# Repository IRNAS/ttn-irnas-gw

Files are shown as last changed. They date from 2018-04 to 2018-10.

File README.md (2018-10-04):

# Build and configure your own LoraWAN Gateway from The Things Conference On Tour in Maribor!

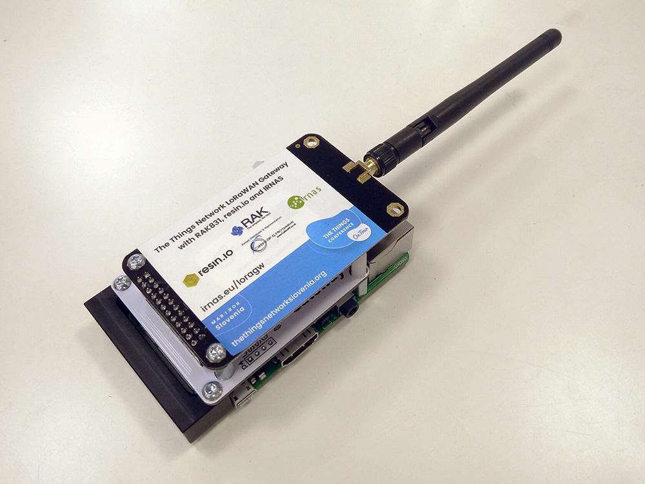
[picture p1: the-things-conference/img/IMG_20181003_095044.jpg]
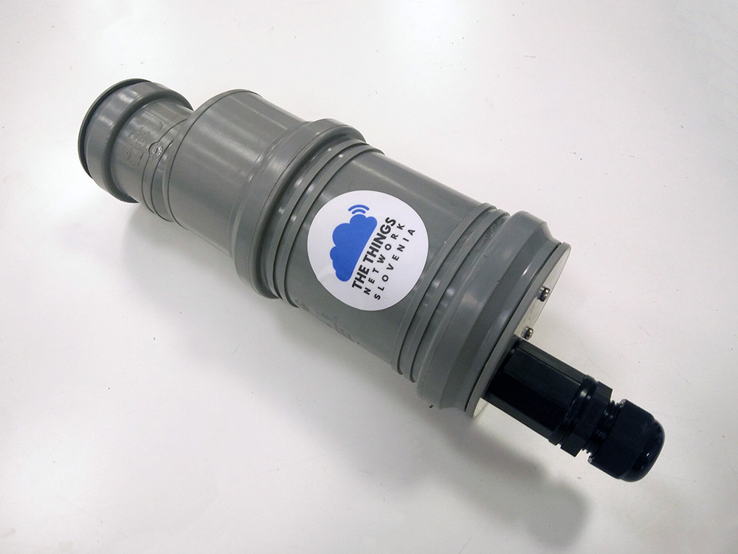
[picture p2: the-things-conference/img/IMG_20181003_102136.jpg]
   **Instructions available [HERE](https://github.com/IRNAS/ttn-irnas-gw/tree/master/the-things-conference/README.md).**

# LoraWAN gateway for TheThingsNetwork

To boost the growth of cost-effective community established outdoor gateways we have designed IRNAS outdoor LoraWAN gateway that includes all components and an antenna element in a weatherproof enclosure. This way communities can easily deploy good quality gateways with minimal costs. Currently there are a number of different designs available:
 1. TheThingsConference Slovenia GW RPi 3b+ using resin.io and RAK831 (latest), optional external antenna, optional 3G uplink
 1. RPi Zero W and RAK831/IMST iC880A

# TheThingsConference Slovenia gateway LoraWAN gateway RAK wireless RAK831, Raspberry Pi 3B+ with resin.io and IRNAS connecting PCB
This gateway desing is the latest in series of the gateways, optimized for simple assembly and reliable outdoor operation. It is available in basic and external antenna configurations:

* Components of basic version
  * RAK wireless RAK831 gateway module http://www.rakwireless.com/en/WisKeyOSH/RAK831 (TheThingsNetwork Conference on Tour Maribor units sponsored by RAK wireless)
  * IRNAS https://github.com/IRNAS/RPi-HAT-RAK831-PoE PCB (TheThingsNetwork Conference on Tour Maribor units sponsored by IRNAS)
  * Raspberry Pi 3B+ (TheThingsNetwork Conference on Tour Maribor units sponsored by resin.io)
  * micro SD card 16GB (TheThingsNetwork Conference on Tour Maribor units sponsored by resin.io)
  * Waterproof PoE connector (TheThingsNetwork Conference on Tour Maribor units sponsored by resin.io)
  * Polyethilene tubing for enclosure (TheThingsNetwork Conference on Tour Maribor units sponsored by resin.io)
  * 24V Passive PoE injector/power supply (TheThingsNetwork Conference on Tour Maribor units sponsored by IRNAS)

* Components of upgrade
  * SMA to N-connector adapter
  * RAK wireless 4dB 868MHz antenna
  * Pipe mounts for installing the GW outdoors

# TheThingsNetwork LoraWAN gateway with RAK831 / IMST iC880A and RaspberryPi Zero W for outdoor use. DIY 5.5dB colinear antenna or N connector antenna.

There are two key design options available, subject to selecting the antenna:
* DIY colinear antenna with designed gain of 5.5dB, typically build quality reducsed this to about 3dB (shown left)
* N-connector option for other antennas, default option is RAK wireless omni glass fiber antenna 6dB (design files to be avilable shortly) (shown right)

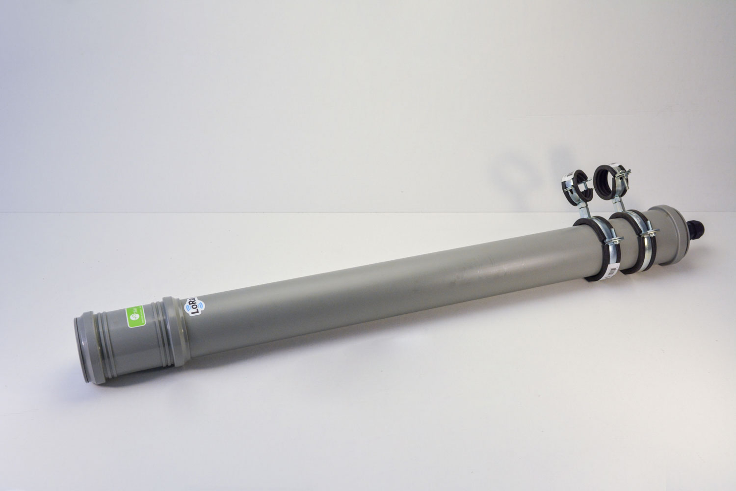
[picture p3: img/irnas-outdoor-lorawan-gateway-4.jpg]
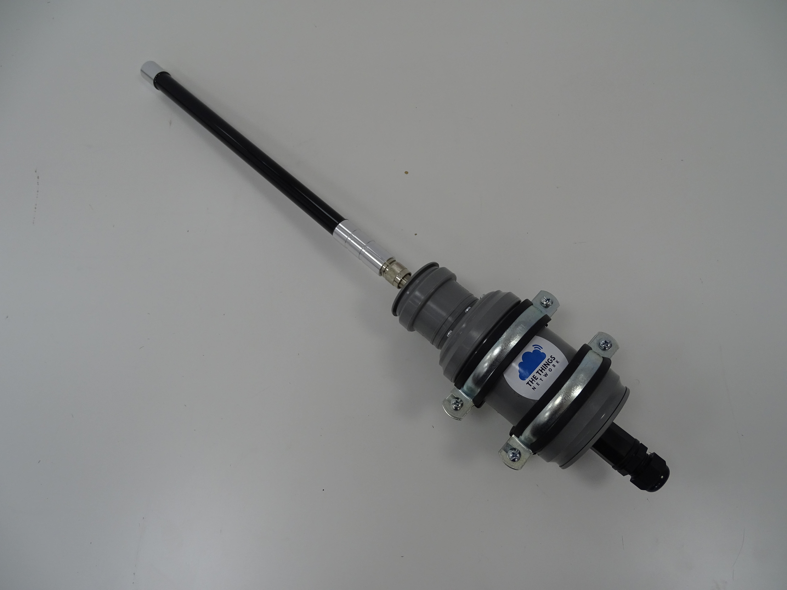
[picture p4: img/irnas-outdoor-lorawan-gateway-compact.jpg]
  

IRNAS outdoor LoraWAN gateway joins great solutions into an unified gateway:

* RAK Wireless RAK831 concentrator option:
  * RAK wireless RAK831 gateway module http://www.rakwireless.com/en/WisKeyOSH/RAK831
  * RAK-Raspberry Pi shield by ch2i https://github.com/hallard/RAK831-Zero

* IMST iC880A concentrator option:
  * IMST ic880A concentrator https://wireless-solutions.de/products/radiomodules/ic880a.html
  * iC880A RPi shield/backplane https://www.tindie.com/products/gnz/imst-ic880a-lorawan-backplane-kit/
  * note this backplane requires a minor manual modification to install Murata OKI-78SR-5 regulator, untill an optimized version is designed, check photosfor details

* Components used in both versions
  * Murata OKI-78SR-5 power regulator (multiple versions available)
  * Raspberry Pi Zero W embedded computer + SD card https://www.raspberrypi.org/products/raspberry-pi-zero-w/
  * micro USB-Ethernet USB 2.0 adapter: https://www.aliexpress.com/item/PZ-USB-2-0-to-fast-Ethernet-10-100-RJ45-Network-LAN-Adapter-Card-Micro-usb/32819958748.html
  * Waterproof PoE injector http://szzq.en.alibaba.com/product/60307069118-209893270/IP67_waterproof_RJ45_ethernet_cable_connector.html
  * DIY 5.5dB co-linear antenna designed by Fabien Ferrero from UNICE in France
  * Polyethilene tubing for enclosure 75mm diameter
  * 3D printed part by IRNAS to mount everything together
  * 24V Passive PoE injector/power supply
  * Optional INA219 current measurement board via I2C

The final product is a simple and and cost-effective gateway for about 250 EUR anyone can make and simply install outdoor. With this design we have achieved over 50 km coverage between Pohorje mountain and cities of Graz in Austria and Zagreb in Croatia.

## Assembly instructions
Assembly instructions are coming up shortly, however the posted images are sufficient for replicating the design. The only custom mechanical part that can be 3D printed or milled available in this repository in the folder: mount and on [this link](https://a360.co/2HcsiBF).

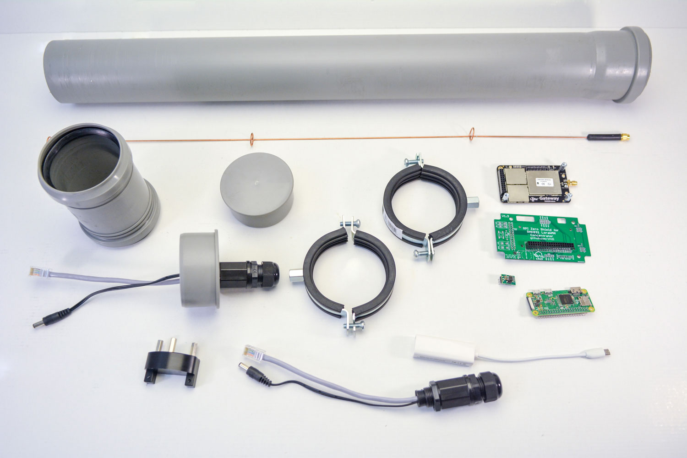
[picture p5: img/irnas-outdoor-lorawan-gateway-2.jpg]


RAK Wireless RAK831 concentrator option

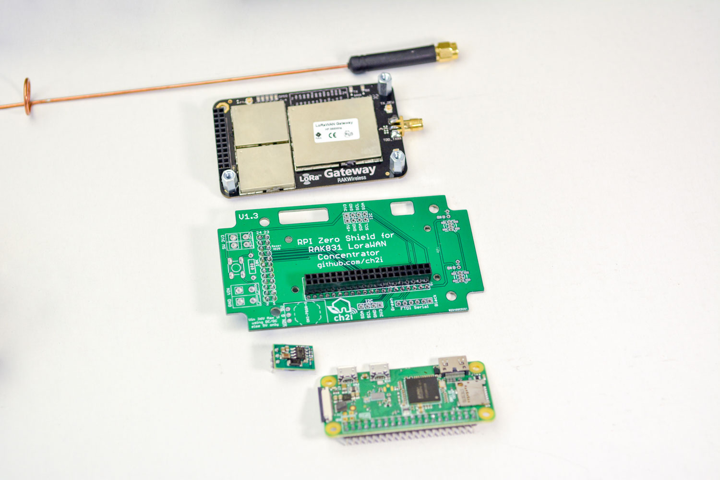
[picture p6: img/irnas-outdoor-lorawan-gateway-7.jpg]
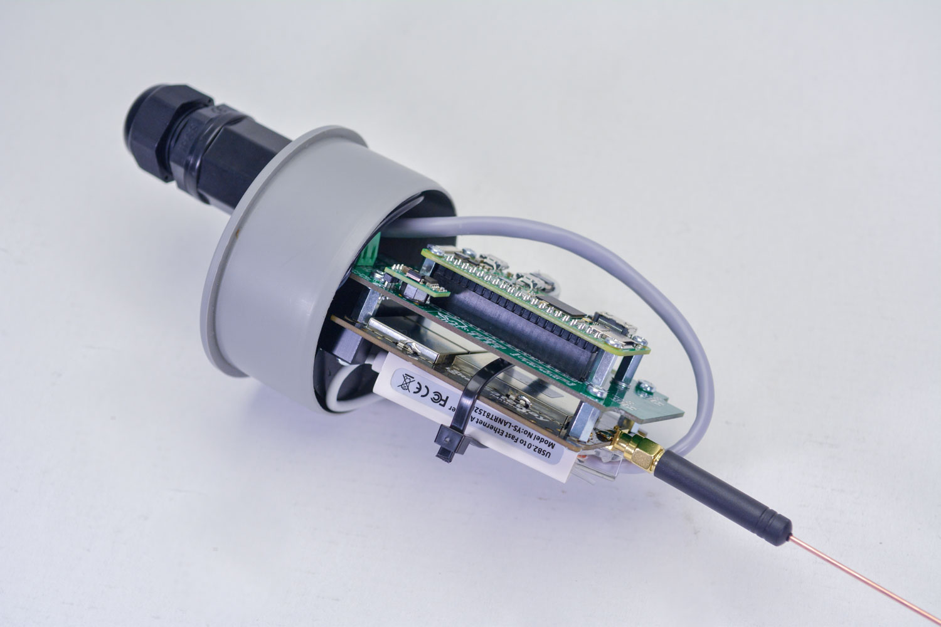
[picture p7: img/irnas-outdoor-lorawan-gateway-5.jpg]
 

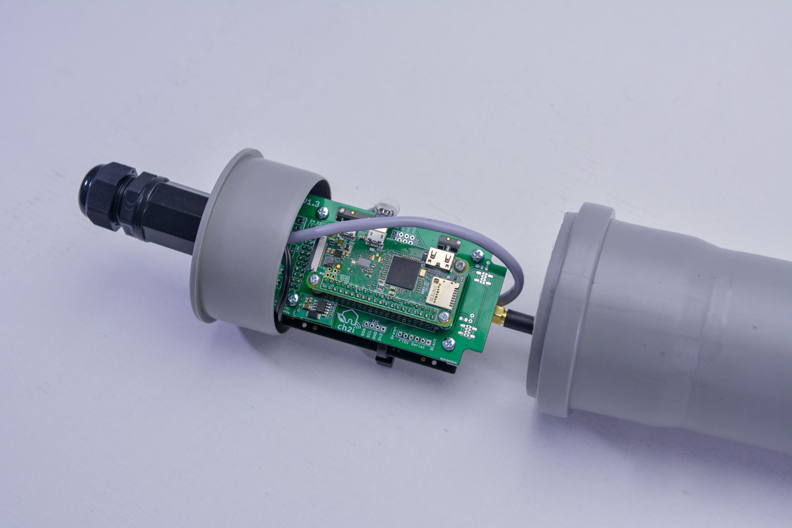
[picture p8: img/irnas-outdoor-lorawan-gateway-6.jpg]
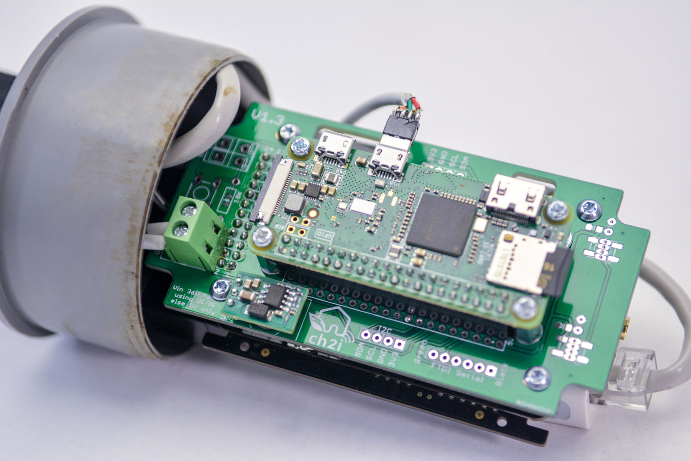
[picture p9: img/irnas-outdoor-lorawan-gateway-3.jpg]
 

IMST iC880A concentrator option

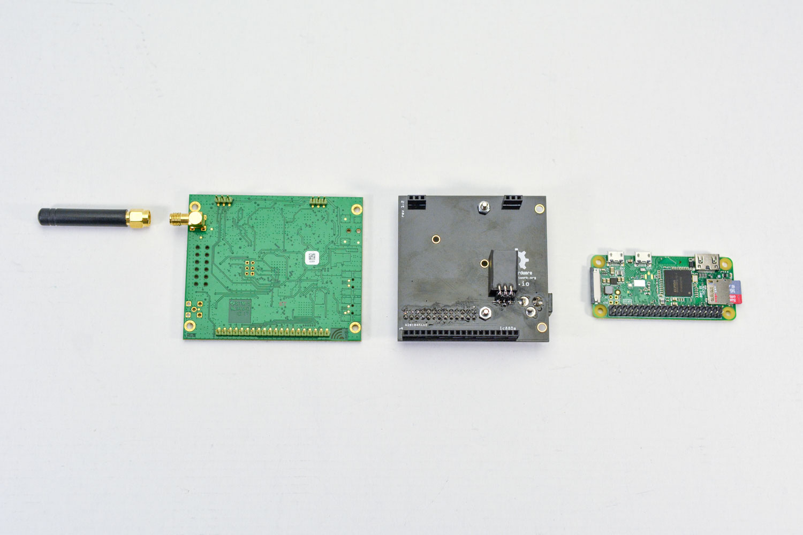
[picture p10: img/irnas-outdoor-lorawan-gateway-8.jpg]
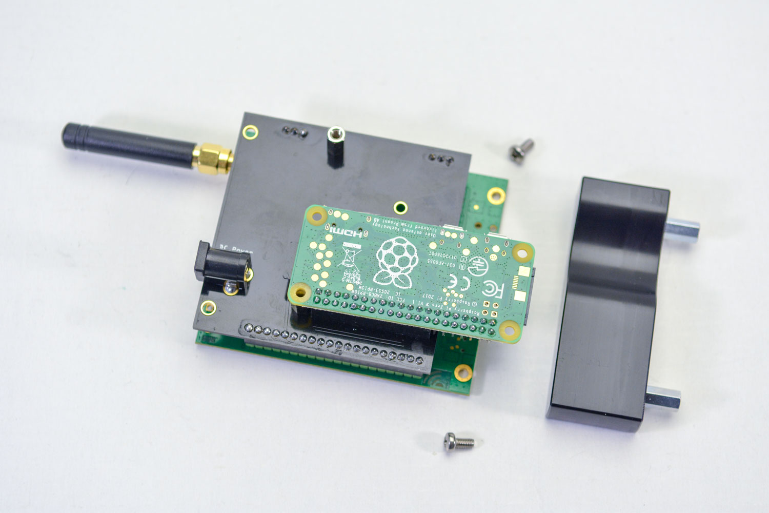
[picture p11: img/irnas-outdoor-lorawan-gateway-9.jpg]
 

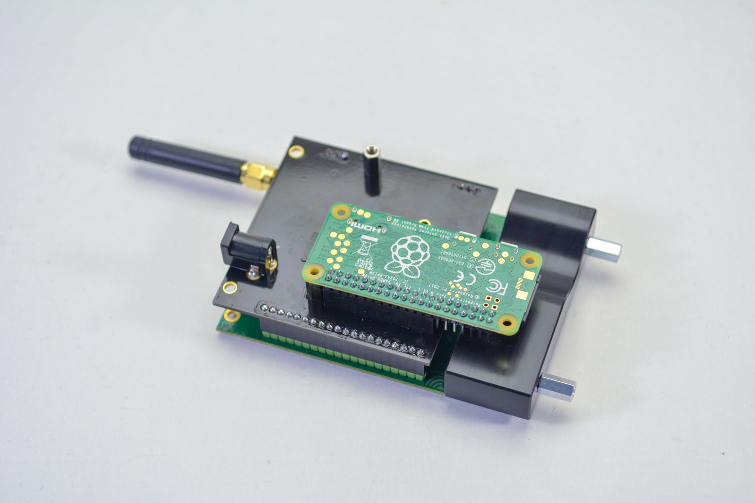
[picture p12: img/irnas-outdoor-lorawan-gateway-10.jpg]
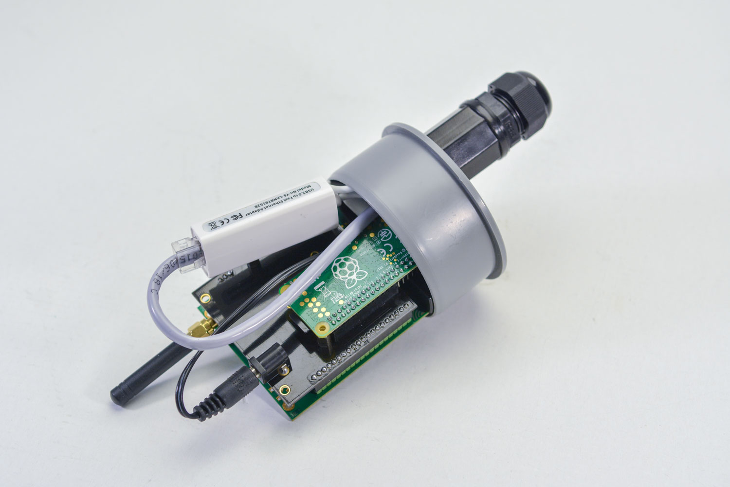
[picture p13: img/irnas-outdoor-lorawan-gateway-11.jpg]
 



## Co-linear antenna wire
Bending the wire for the co-linear 5.5dB antenna is likely the most challenging part and requires special care. Note that the frequency is tuned with the diameter of the loop and thus it must be made rather precisely. There are two antenna designs available, [one for 868MHZ EU](Collinear868MHzLoRaantenna.PDF) and [the other for 915MHz USA](CollinearLoRaantenna915MHzIRNAS.pdf). Step-by-step instructions on how to make the antenna available in this [video tutorial](https://youtu.be/1_1LxuOngHs).

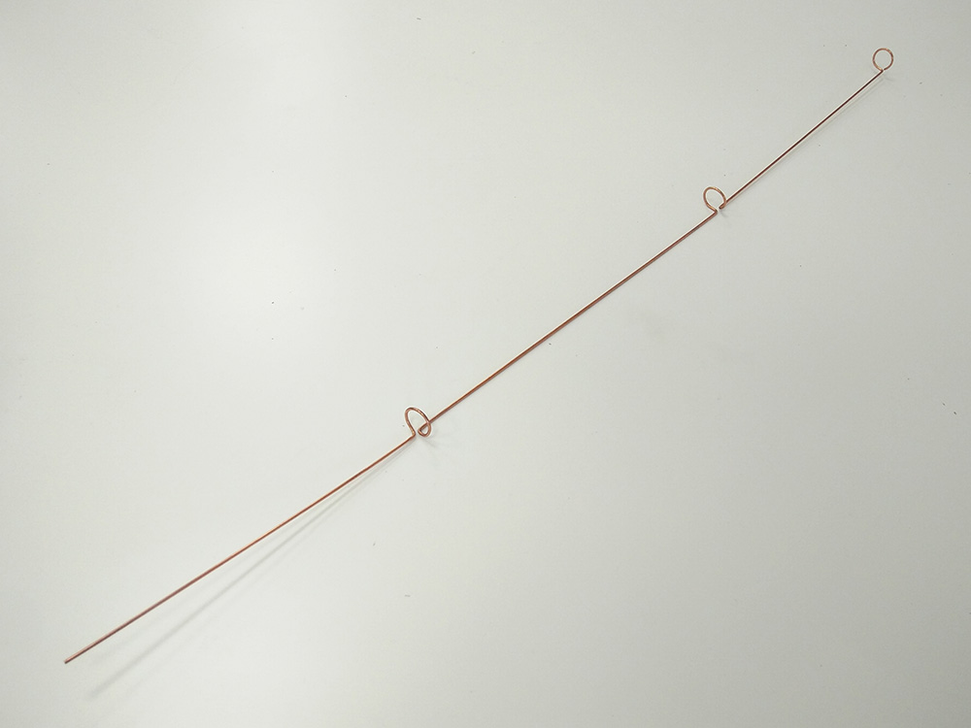
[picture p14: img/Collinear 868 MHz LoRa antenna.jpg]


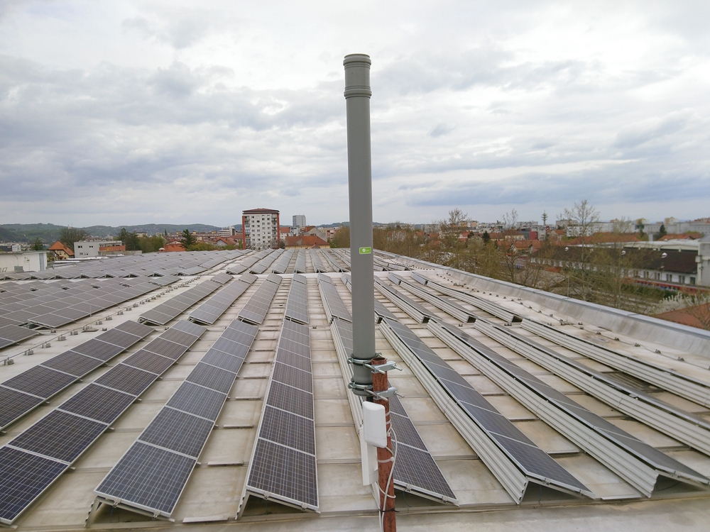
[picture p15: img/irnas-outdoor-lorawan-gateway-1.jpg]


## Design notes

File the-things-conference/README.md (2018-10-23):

# LoraWAN Gateway configuration

Slides from the workshop at The Things Conference On Tour in Maribor that will help you to configure your own LoraWAN gateway are available [HERE](https://speakerdeck.com/pimterry/build-your-own-ttn-gateway-with-resin-dot-io-and-rak-wireless). If you need any help or have any questions do not hesitate to [contact us](https://www.irnas.eu/contact/).

 

:warning: ***Attention: There is a mistake on the slides from the workshop. On the slide 12 of the instructions the GW_RESET_PIN is set to 11 but it should be set to 22 instead.***

# Assembly instructions for waterproof housing

The next steps will help you to assemble the waterproof housing for the LoraWAN Gateway and prepare it for the outdoor mounting.

Take the assembled electronics stack, consisting of Raspberry Pi and RAK Wireless RAK831 concentrator.

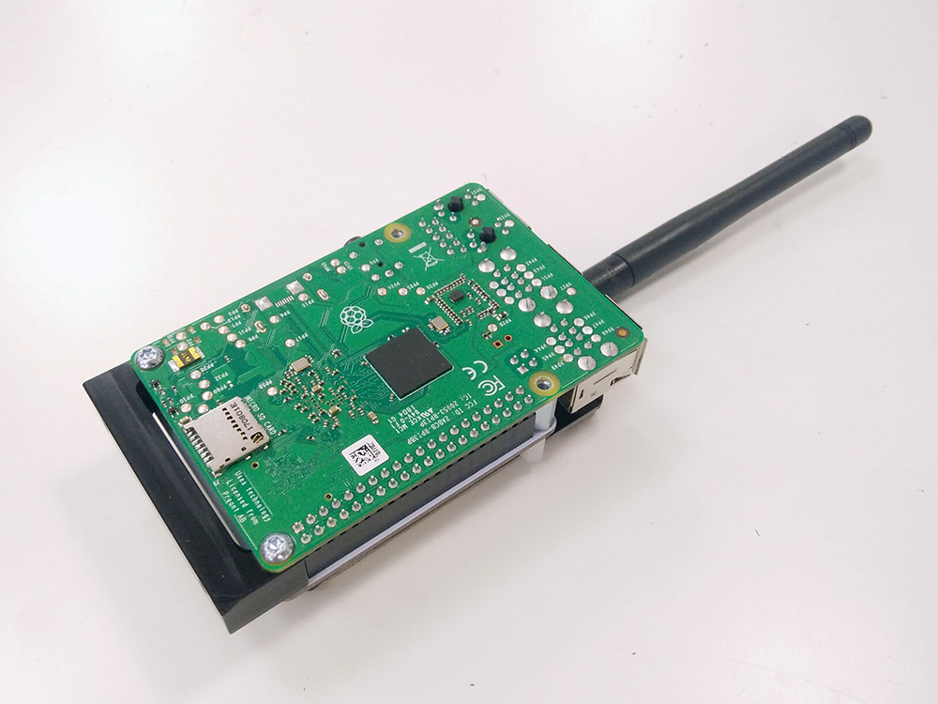
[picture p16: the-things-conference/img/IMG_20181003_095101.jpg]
 

Prepare and insert the micro SD card into the Raspberry Pi.

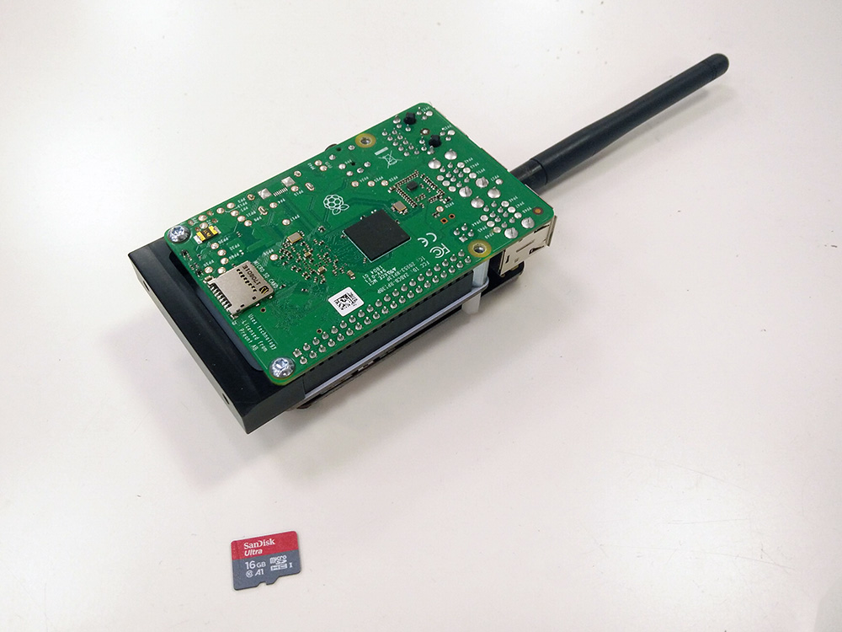
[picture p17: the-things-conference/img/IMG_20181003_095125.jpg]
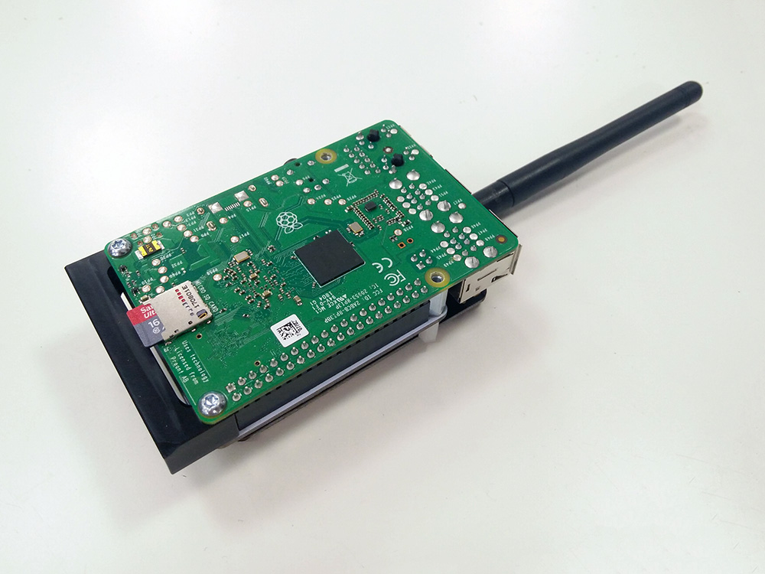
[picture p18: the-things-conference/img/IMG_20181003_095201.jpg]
 

Take the larger plastic lid and attach the ethernet cable gland.

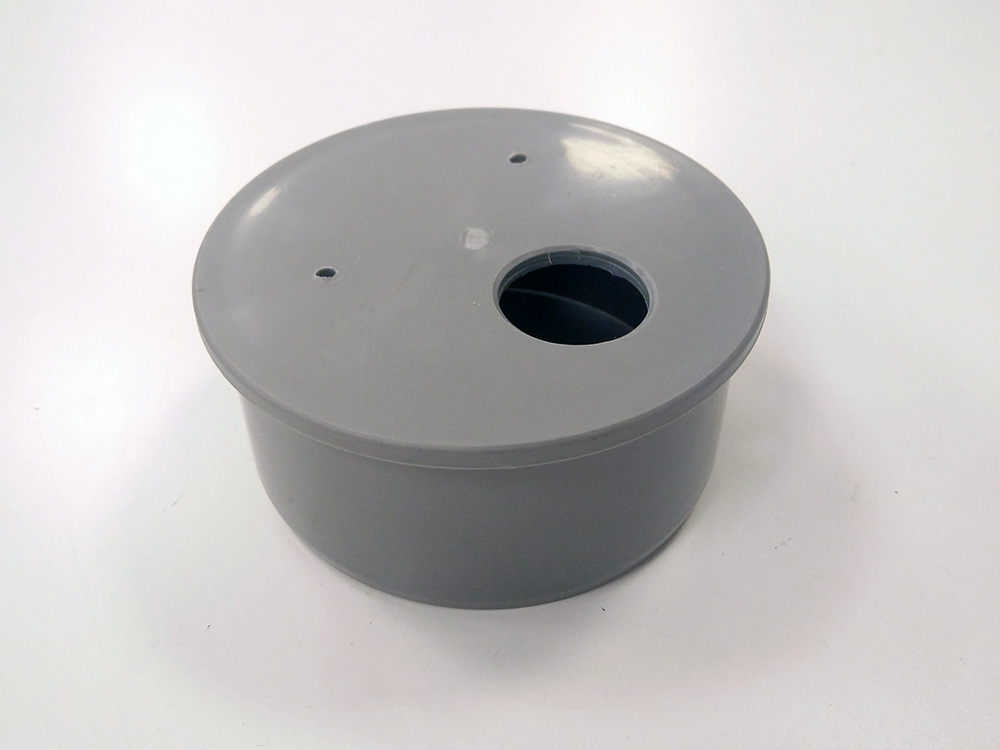
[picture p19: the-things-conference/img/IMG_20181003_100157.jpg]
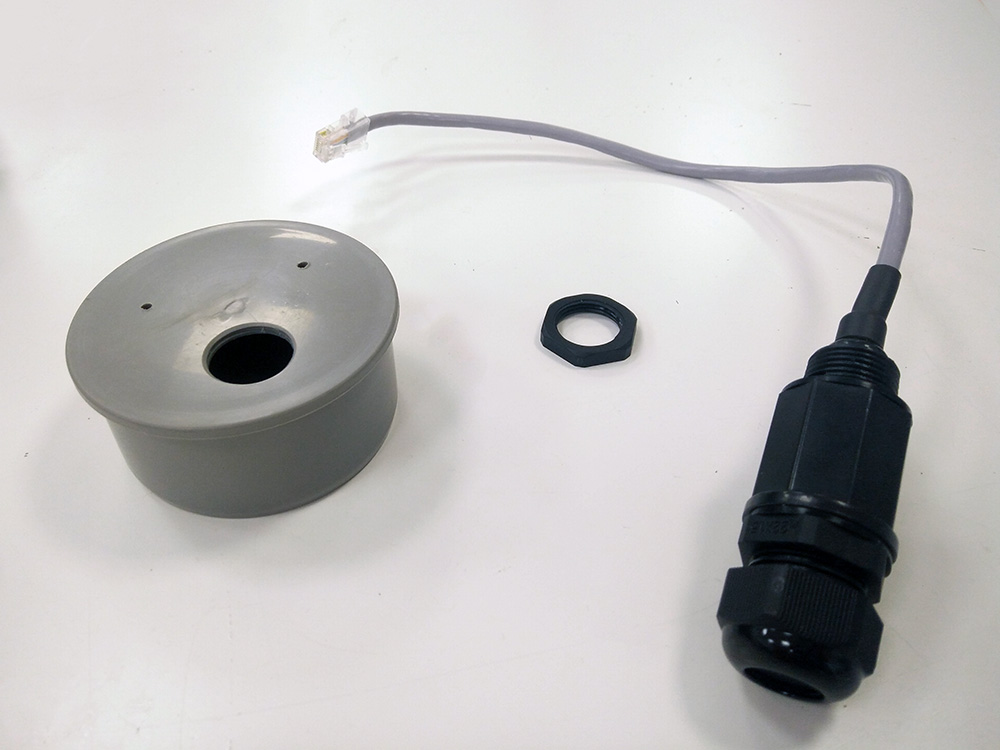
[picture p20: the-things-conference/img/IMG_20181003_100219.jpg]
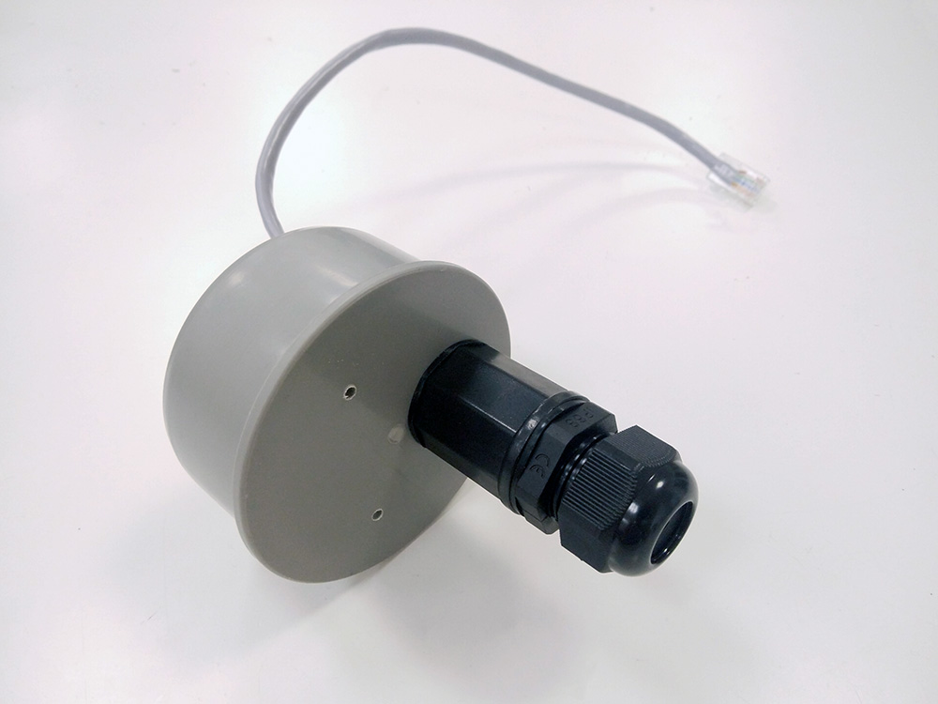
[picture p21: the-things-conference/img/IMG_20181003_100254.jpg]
  

Attach the electronics stack using two screws (size M3x5).

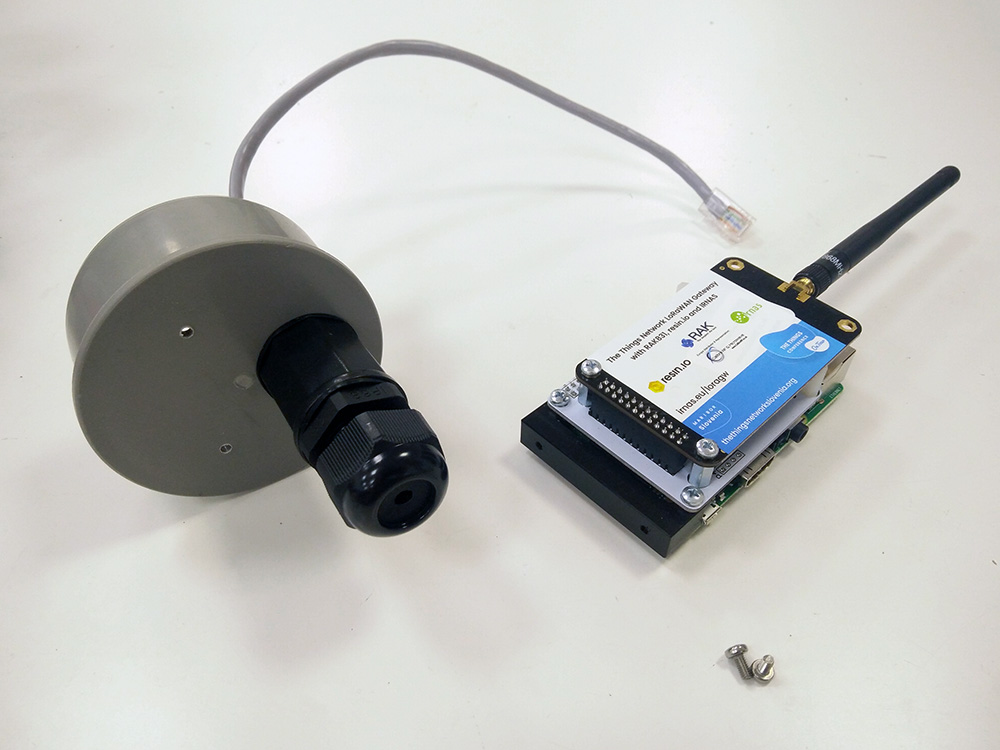
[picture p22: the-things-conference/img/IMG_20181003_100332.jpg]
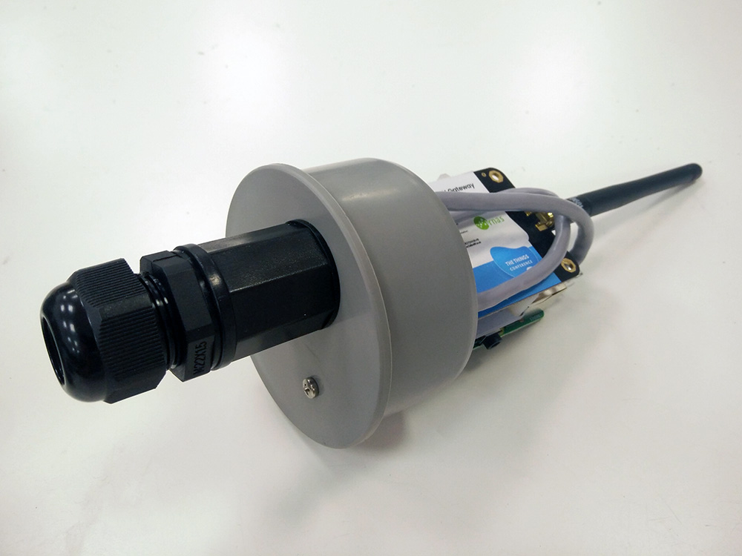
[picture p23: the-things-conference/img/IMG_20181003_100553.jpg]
 

Take the remainig parts of plastic housing and insert the smaler lid into the smaler tube.

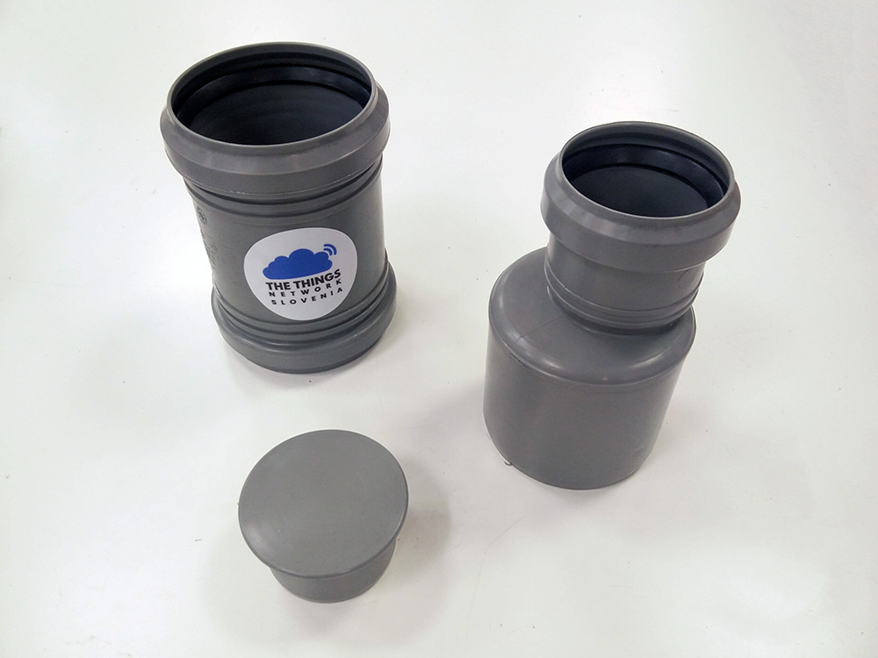
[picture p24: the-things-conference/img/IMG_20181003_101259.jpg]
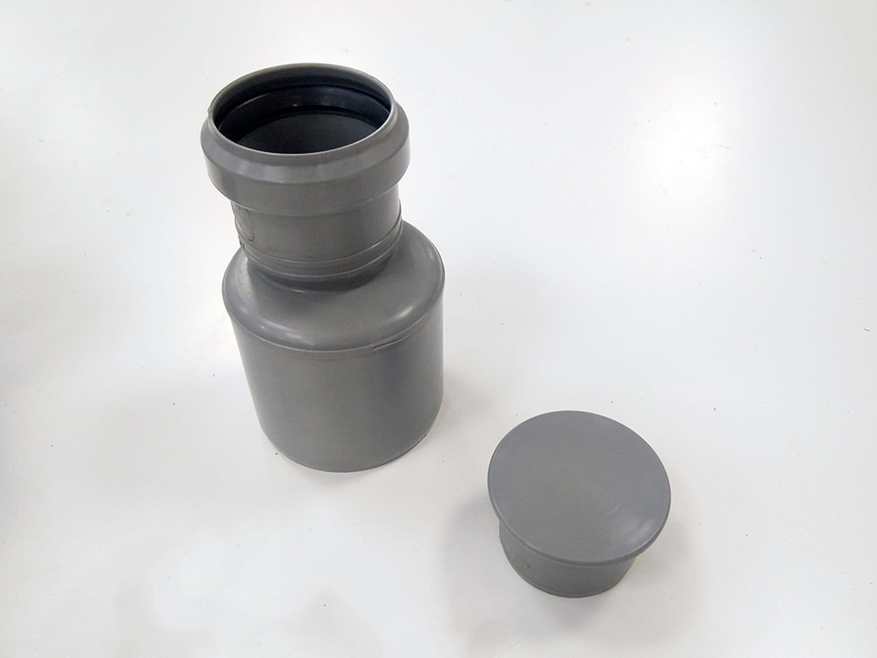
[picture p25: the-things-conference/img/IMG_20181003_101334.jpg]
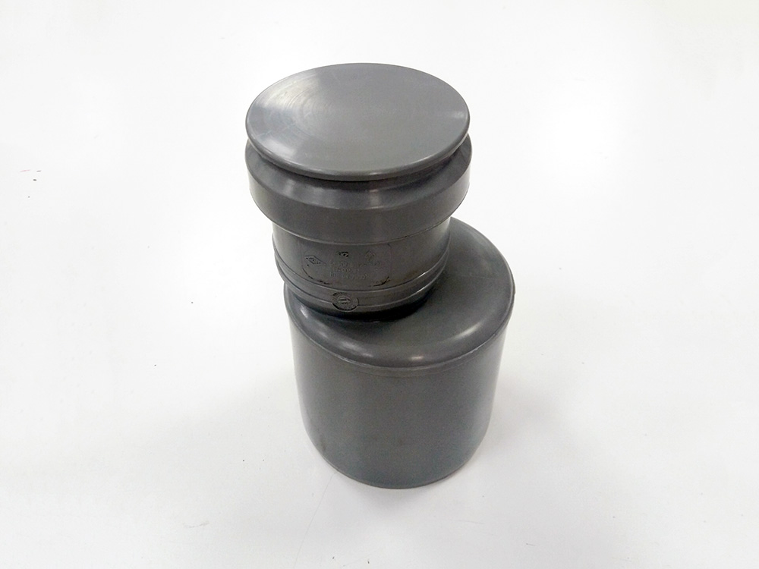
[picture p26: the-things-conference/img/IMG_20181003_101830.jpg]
  

Insert the larger lid with electronics into the larger tube.

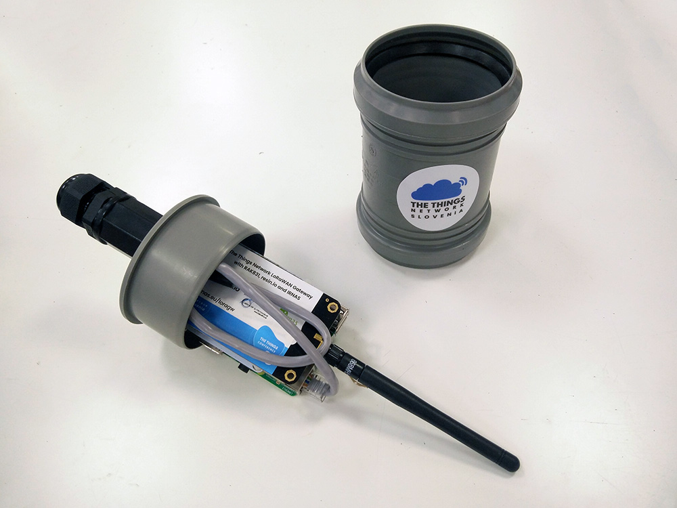
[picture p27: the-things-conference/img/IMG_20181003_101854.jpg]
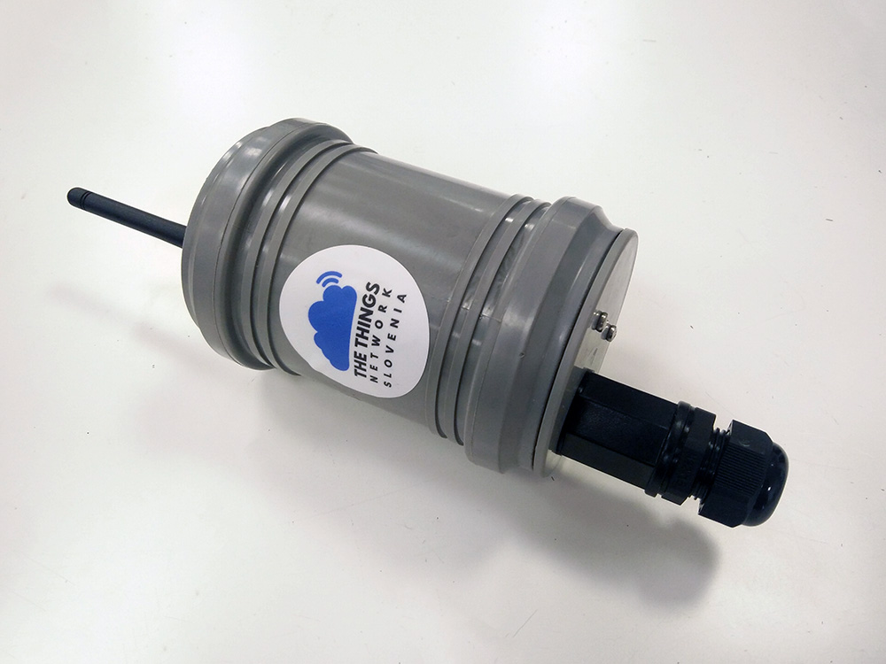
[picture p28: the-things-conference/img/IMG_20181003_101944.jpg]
 

Insert the smaler tube into the larger tube. Be careful not to damage the antenna - DO NOT insert the smaller tube all the way into the larger tube.

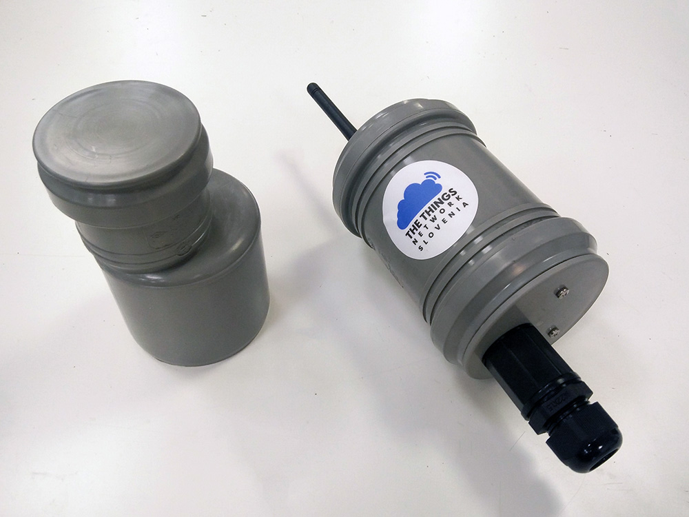
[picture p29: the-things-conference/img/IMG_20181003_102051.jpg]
 

## External antenna upgrade

The next steps will help you to assemble and attach the external antenna upgrade kit. If you would like to upgrade your LoraWAN Gateway with an external antenna please [contact us](https://www.irnas.eu/contact/).

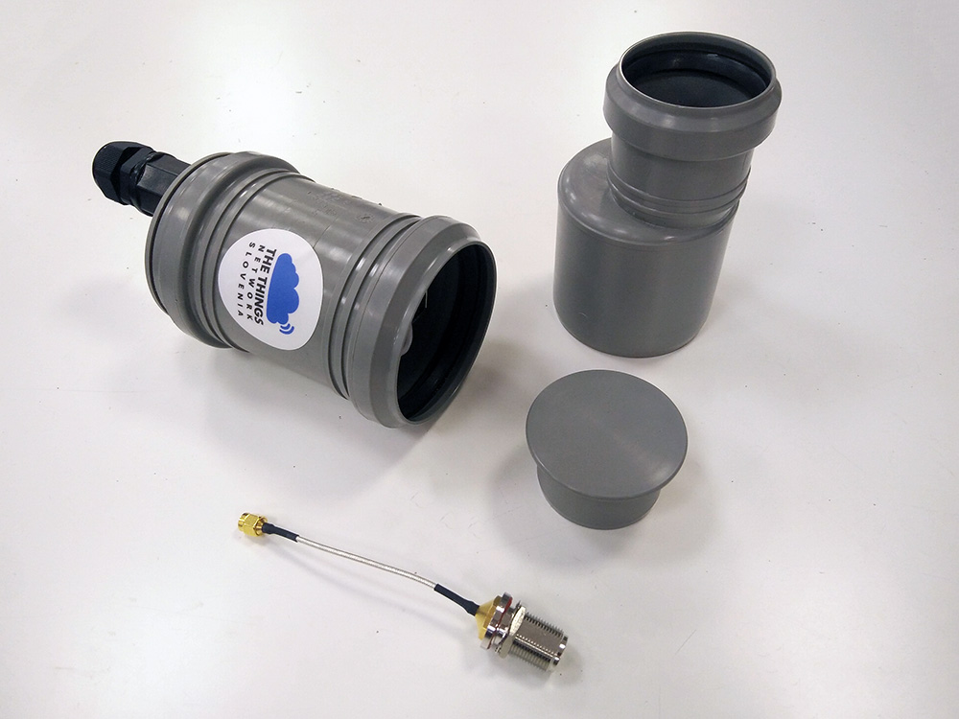
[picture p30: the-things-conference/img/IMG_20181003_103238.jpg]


Take the smaller lid and drill a hole in the center of the lid.

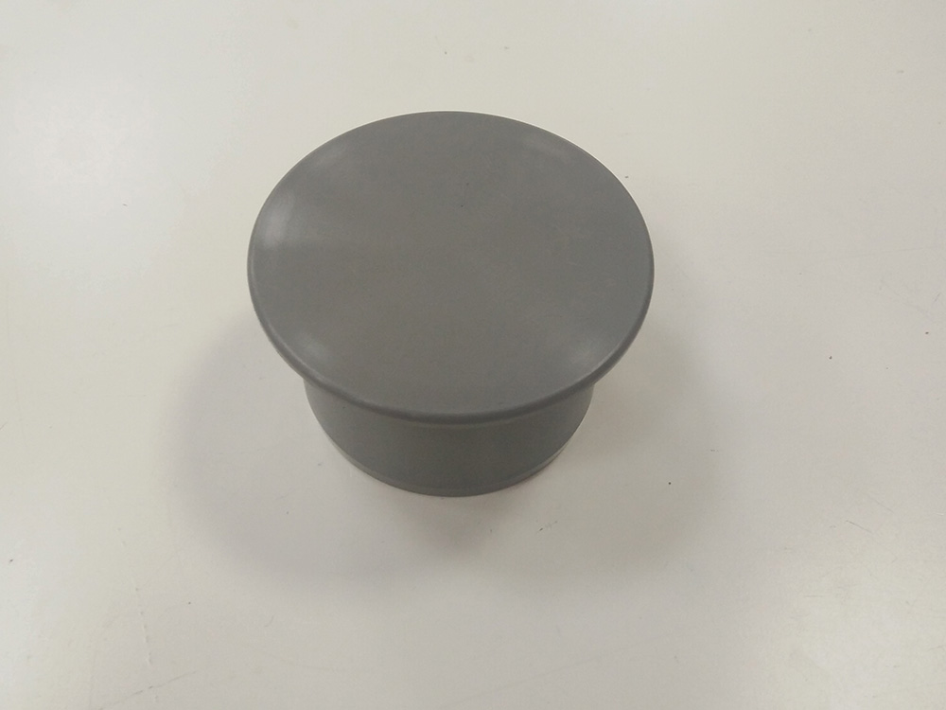
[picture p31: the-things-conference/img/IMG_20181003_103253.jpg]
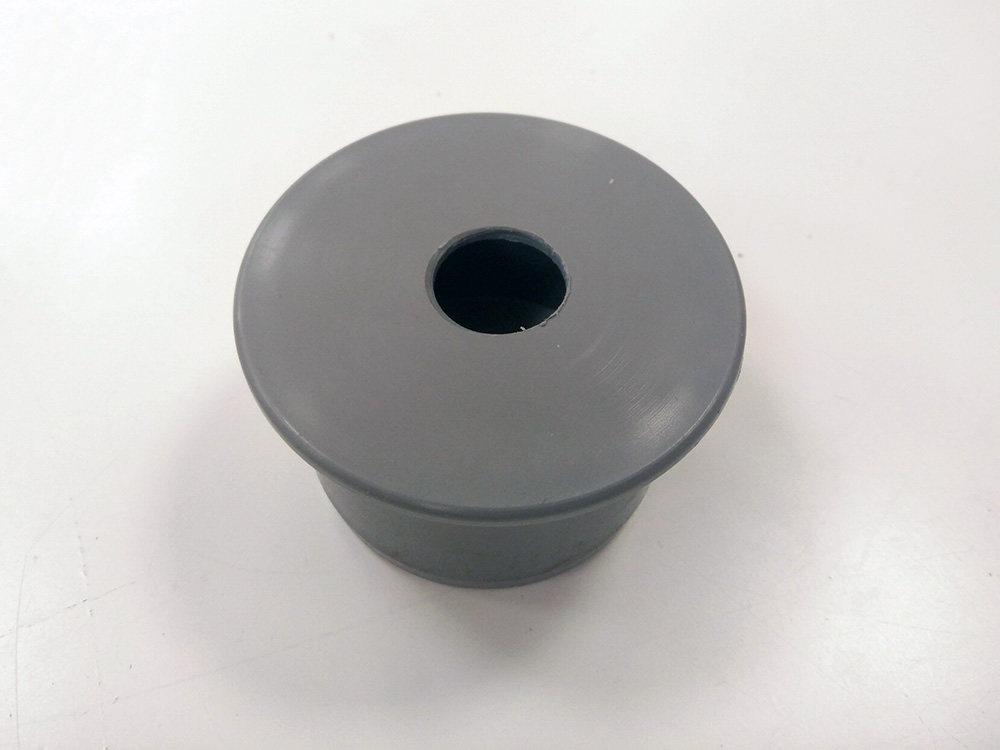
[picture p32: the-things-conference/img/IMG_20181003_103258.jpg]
 

Connect the antenna adapter to the RAK Wireless RAK831 concentrator.

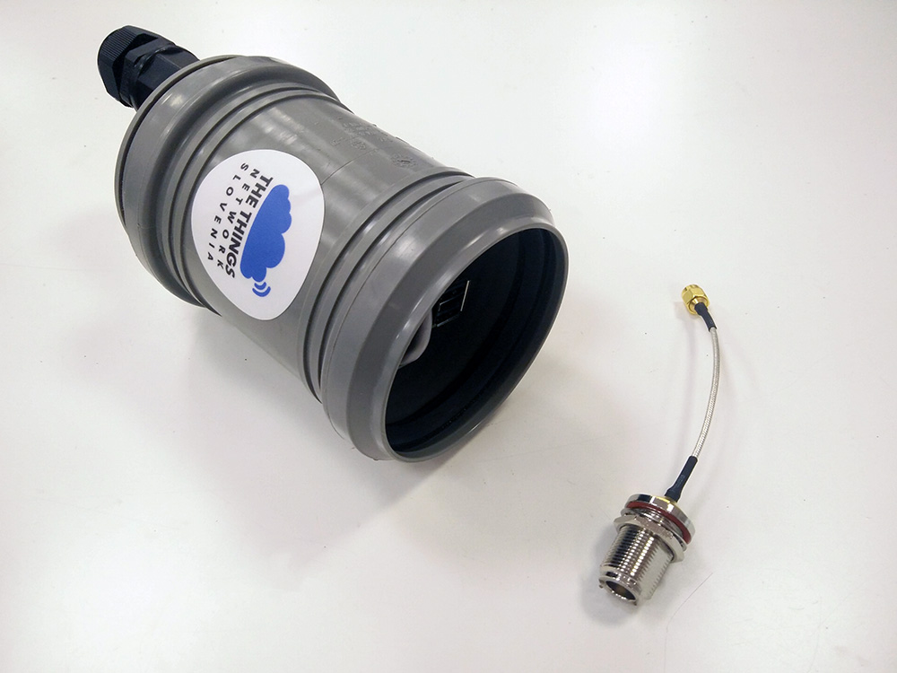
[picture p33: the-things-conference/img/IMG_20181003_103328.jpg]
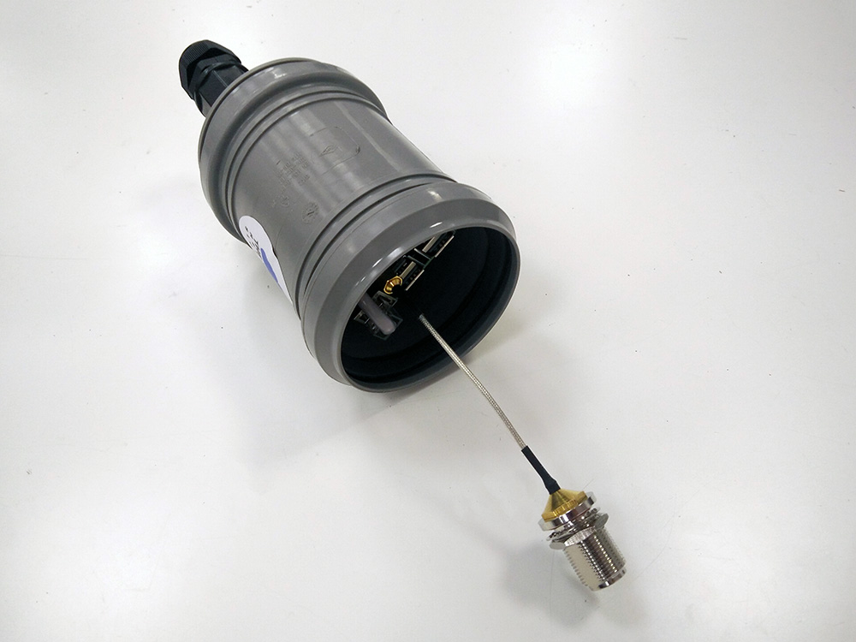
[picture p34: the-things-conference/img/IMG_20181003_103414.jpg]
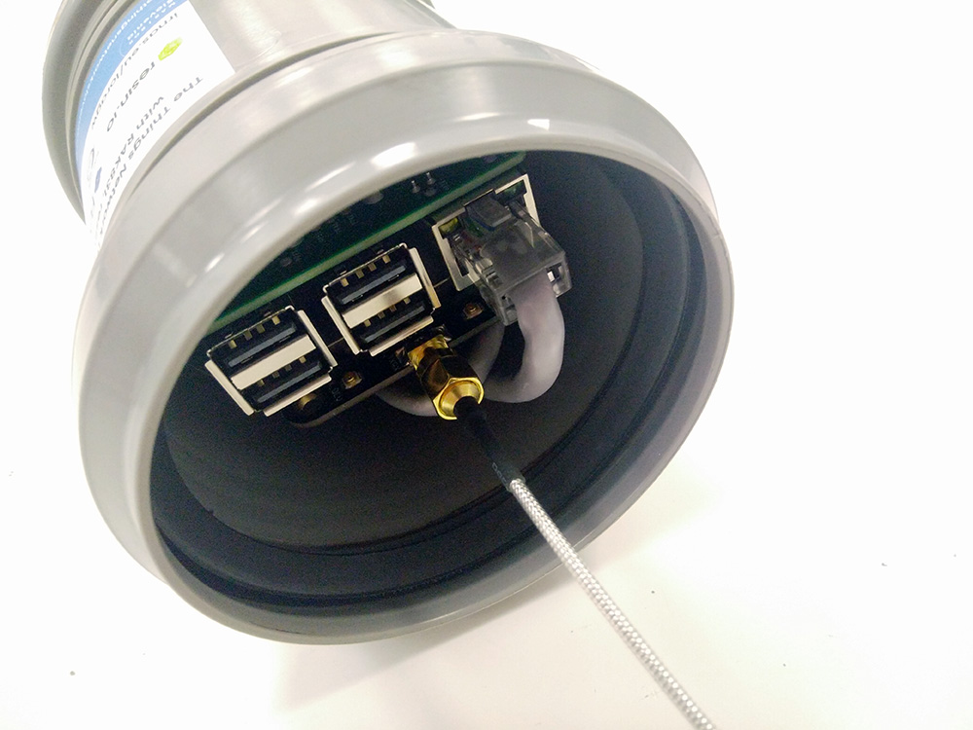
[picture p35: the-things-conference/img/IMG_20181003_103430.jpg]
  

Insert the smaller tube all the way into the larger tube.

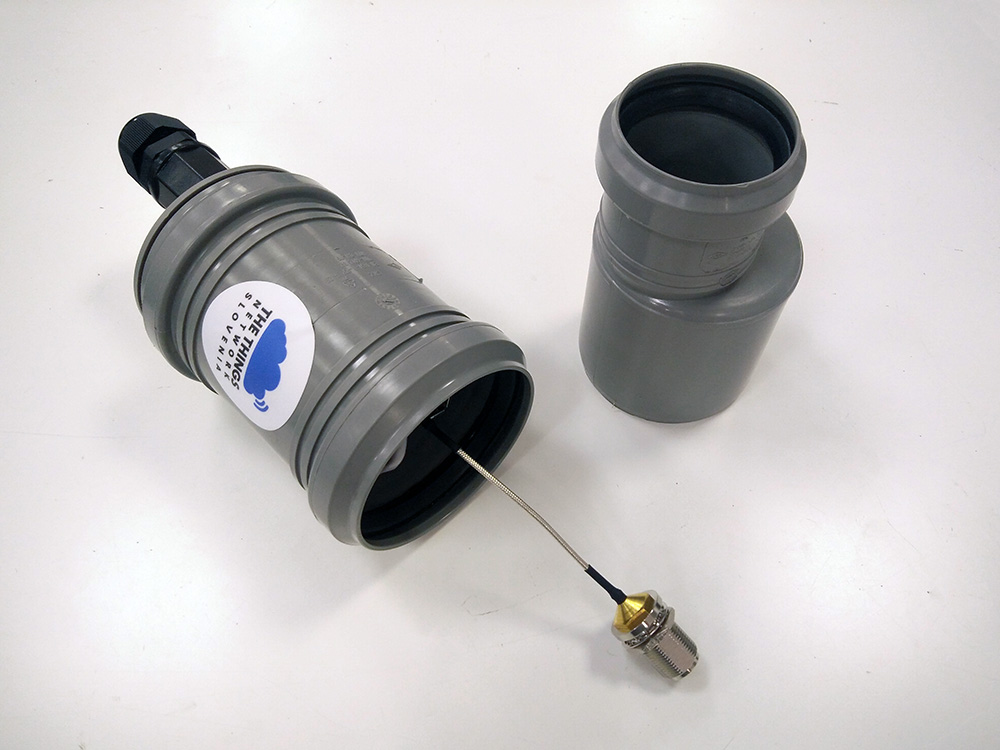
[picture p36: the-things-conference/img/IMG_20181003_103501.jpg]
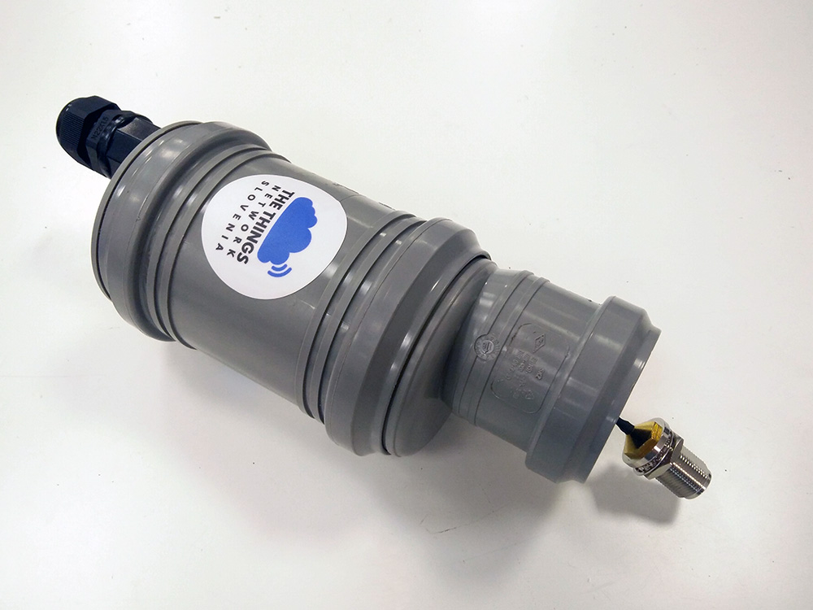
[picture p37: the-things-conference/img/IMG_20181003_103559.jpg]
 

Attach the antenna adapter to the smaler lid and insert the smaller lid into the tube.

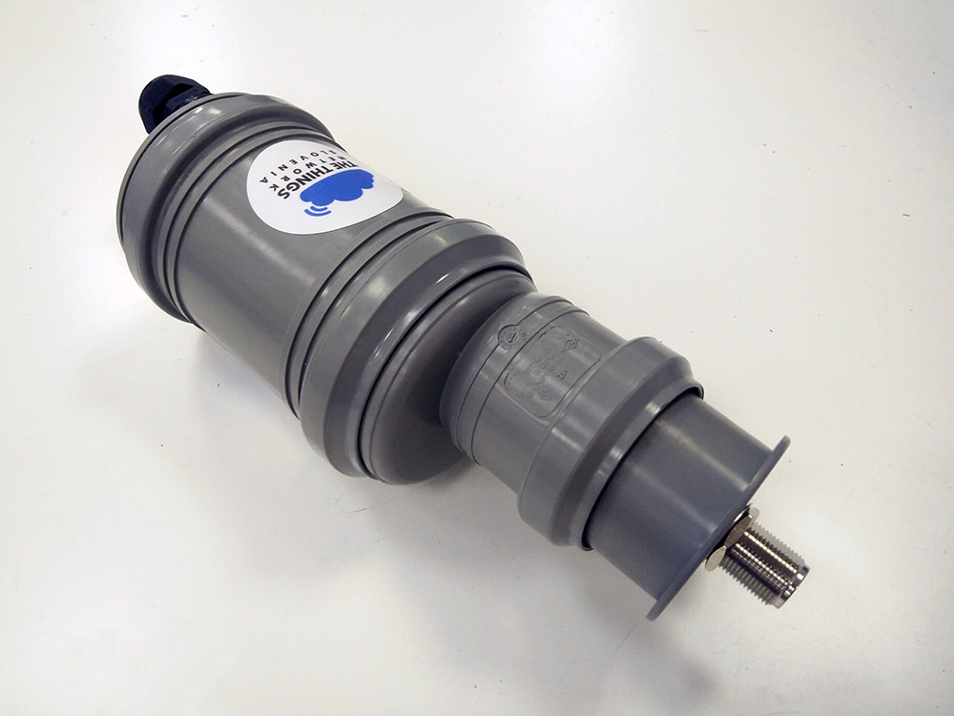
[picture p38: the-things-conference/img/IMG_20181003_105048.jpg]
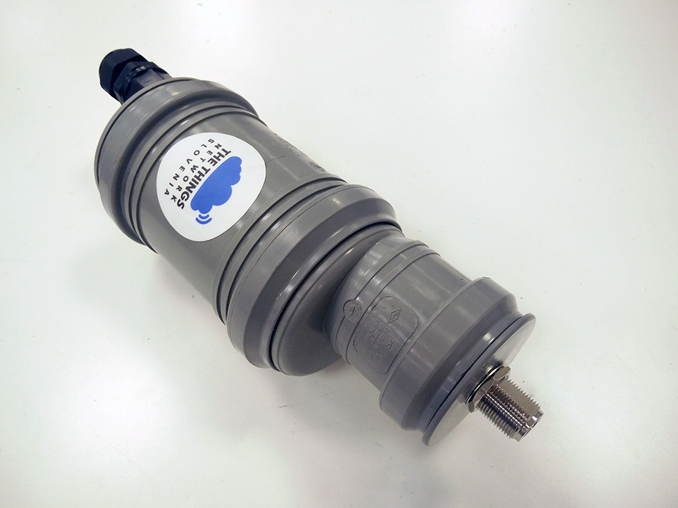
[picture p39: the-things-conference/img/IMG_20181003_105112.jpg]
 

Attach the antenna.



## Mounting upgrade

The next steps will help you to assemble and attach the mounting upgrade kit. If you would like to upgrade your LoraWAN Gateway with a mounting kit please [contact us](https://www.irnas.eu/contact/).

Assemble monuting clips.

 

Attach the mounting clips onto the gateway housing.



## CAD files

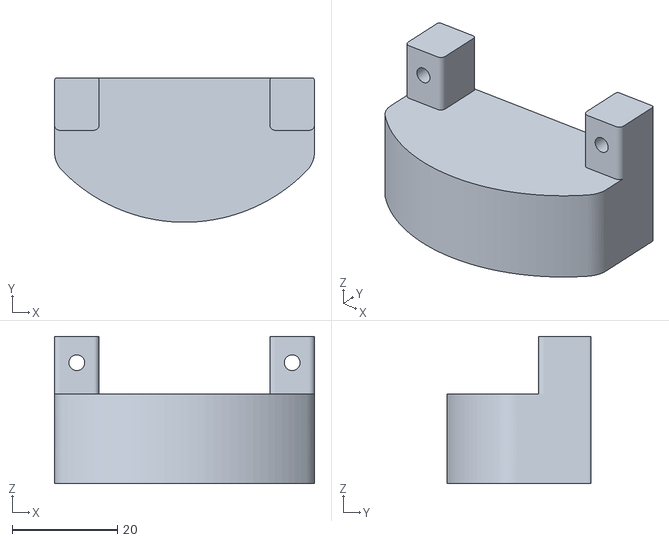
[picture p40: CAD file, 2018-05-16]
mount/lora antena base 1.stl
49.5 x 27.5 x 28.0

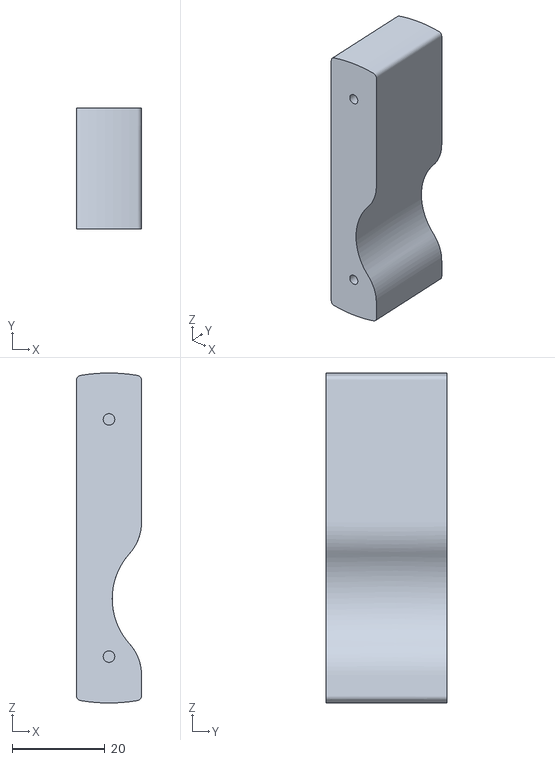
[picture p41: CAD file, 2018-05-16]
mount/lora antena base 2.stl
14.0 x 26.0 x 71.0

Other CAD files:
mount/Lora base piece.step
mount/Lora base piece.stl

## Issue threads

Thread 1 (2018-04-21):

Link to PoE adapter?

terrillmoore, 2018-04-21:
Lovely project!  I was following links, and I notice that the following link is incomplete:

> - USB-Ethernet adapter and Waterproof PoE injector https://www.aliexpress.com/item/High-Quality-5-Pin-Micro-USB-2-0-To-RJ45-LAN-Ethernet-Network-Adapter-100Mbps-For/32789232255.html

The link leads to the USB-Ethernet adapter, but that page doesn't have a PoE adapter.

--Terry

RussNelson, 2018-04-21:
I ordered this one, which seems to be what they're using: https://www.aliexpress.com/item/RJ45-PoE-Splitter-Separator-Female-male-Output-Connector-Plug-Power-Over-Ethernet-Outdoor-Waterproof-Adapter-Cable/32779527743.html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

RussNelson, 2018-04-21:
That's a passive splitter. Just routes the power over the unused Ethernet pairs. I also ordered these two from Amazon: https://www.amazon.com/gp/product/B007Q87KP2/ref=oh_aui_detailpage_o00_s00?ie=UTF8&psc=1
and https://www.amazon.com/gp/product/B01K4S7AEG/ref=oh_aui_detailpage_o02_s00?ie=UTF8&psc=1
They are standards-compliant and transmit 15W @12V using 48V.
The standard requires signalled power-on and short protection, whereas the passive splitter is just wires. That's reflected in the 6X multiplier to get standards compliance.

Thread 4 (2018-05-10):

Ethernet micro-usb cable?

RussNelson, 2018-05-10:
Has the Ethernet micro-usb connector housing been cut down? Maybe a right-angle micro to micro usb adapter would be a good idea? Like these guys: https://www.amazon.com/Ksmile%C2%AE-Right-Degree-Female-Adapters/dp/B01C6031MA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

RussNelson, 2018-05-11:
It looks like the cable should fit just fine if the board is mounted all the way to one side of the pipe. I'm working on my own 3D printed part to hold the three-board assembly.

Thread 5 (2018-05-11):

board holder in OpenSCAD

RussNelson, 2018-05-11:
Needs two of these. Probably prints a LOT faster than the one pictured elsewhere in the project.

[irnas-mount.scad.zip](https://github.com/IRNAS/ttn-irnas-gw/files/1996525/irnas-mount.scad.zip)

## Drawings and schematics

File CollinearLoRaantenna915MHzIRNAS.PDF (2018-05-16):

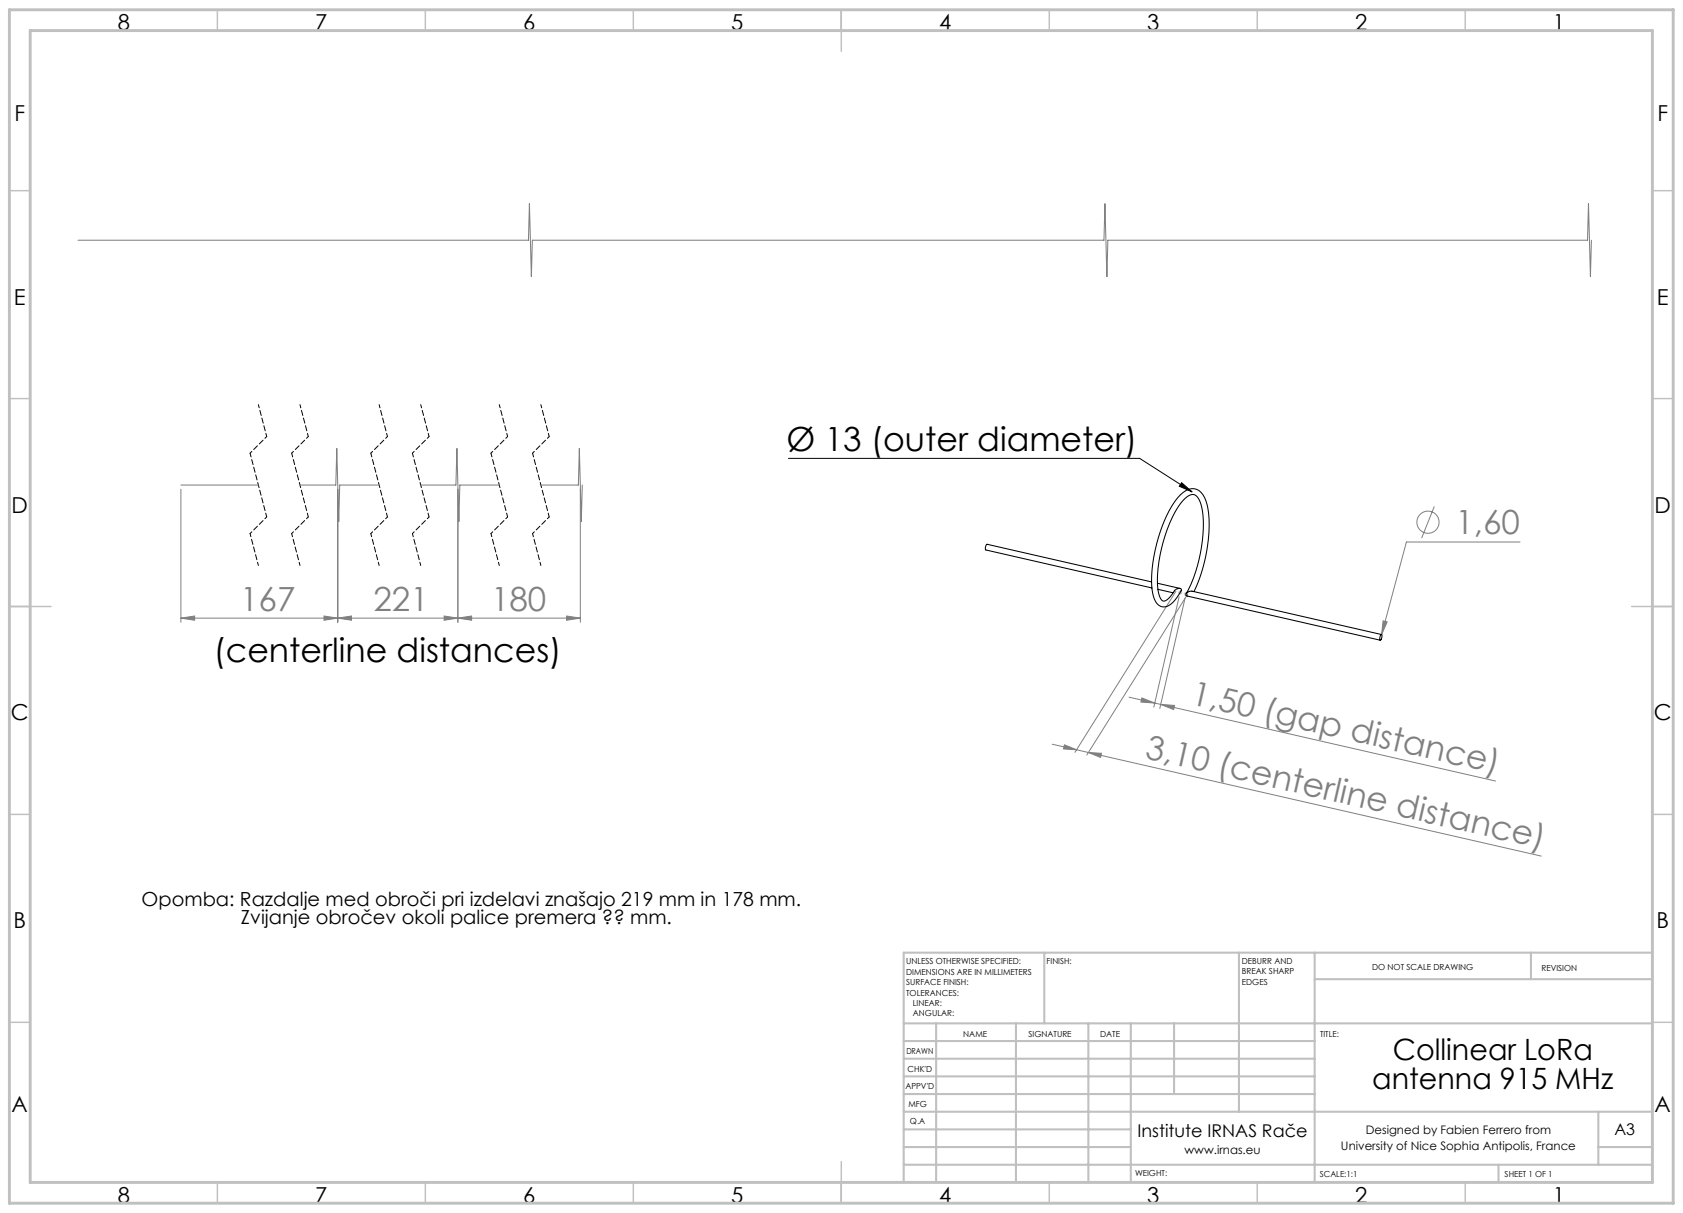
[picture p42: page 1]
3,10 (centerline distance); 1,50 (gap distance); Ø 13 (outer diameter); (centerline distances); FINISH:; DEBURR AND; BREAK SHARP; DO NOT SCALE DRAWING; REVISION; SCALE:1:1; SHEET 1 OF 1

Opomba: Razdalje med obroči pri izdelavi znašajo 219 mm in 178 mm. Zvijanje obročev okoli palice premera ?? mm.

UNLESS OTHERWISE SPECIFIED:
DIMENSIONS ARE IN MILLIMETERS
SURFACE FINISH:
TOLERANCES:
LINEAR:
ANGULAR:

NAME | SIGNATURE | DATE | | | | TITLE: Collinear LoRa antenna 915 MHz

DRAWN
CHK'D
APPV'D
MFG
Q.A | | | | Institute IRNAS Rače www.irnas.eu | Designed by Fabien Ferrero from University of Nice Sophia Antipolis, France | A3

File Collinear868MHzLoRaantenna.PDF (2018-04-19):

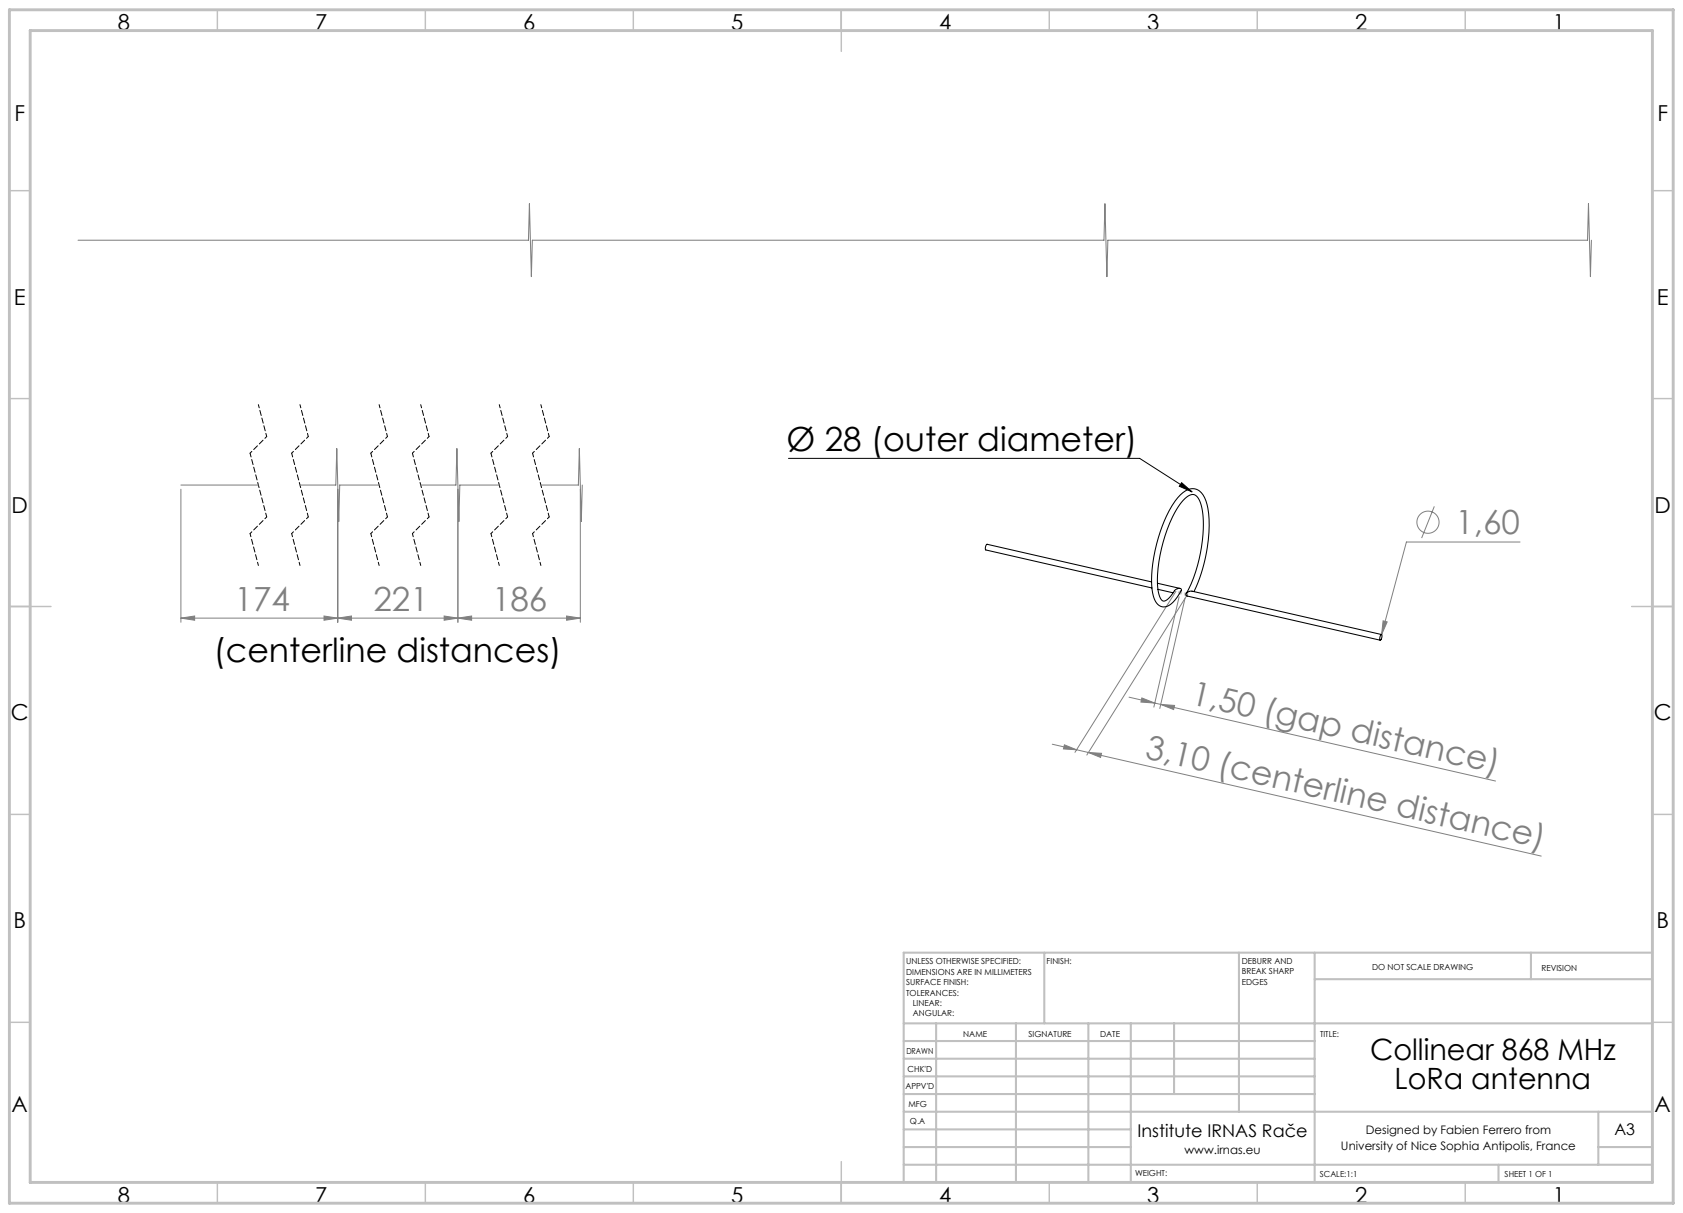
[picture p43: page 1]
3,10 (centerline distance); 1,50 (gap distance); Ø 28 (outer diameter); (centerline distances); FINISH:; DEBURR AND; BREAK SHARP; DO NOT SCALE DRAWING; REVISION; SCALE:1:1; SHEET 1 OF 1

UNLESS OTHERWISE SPECIFIED:
DIMENSIONS ARE IN MILLIMETERS
SURFACE FINISH:
TOLERANCES:
LINEAR:
ANGULAR:

NAME | SIGNATURE | DATE | | | | TITLE: Collinear 868 MHz LoRa antenna

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
